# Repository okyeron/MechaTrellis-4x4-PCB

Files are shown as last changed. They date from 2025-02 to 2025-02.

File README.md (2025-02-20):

## MechaTrellis RGB Driver PCB for 4x4 Keypad PCB

PCB files for the MechaTrellis 4x4 keypad PCB. Format is Kicad 8.0 schematic and board layout

### Description

MechaTellis is an Adaptation/Remix of the Adafruit NeoTrellis RGB Driver PCB.  

MechaTellis was designed by Steven Noreyko/denki-oto. Original NeoTrellis design by Limor Fried/Ladyada for Adafruit Industries. 

These run the same NeoTrellis seesaw I2C chip and are fully software compatible with the NeoTrellis boards and projects.

A JST-SH 4-pin connector is included that will give you power+data access. Note JST-SH is smaller than the NeoTrellis JST-PH connector.

From the original NeoTrellis 4x4 boards:  

These 4x4 button pad boards are fully tile-able and communicate over I2C. With 5 address pins, you've got the ability to connect up to 32 together in any arrangement you like. [With our trusty seesaw I2C-to-anything chip](https://learn.adafruit.com/adafruit-seesaw-atsamd09-breakout), you don't even need to manage the NeoPixel driving. That's right! Both the button management and LED driving is completely handled for you all over plain I2C. With both Arduino/C++ and CircuitPython/Python library support, you can use these pads with any and all microcontroller or computer boards.

**You can tile up to 32 boards together by soldering them edge-to-edge and soldering closed the I2C address jumpers, then use one I2C connection for all tiled boards!**

### License

Creative Commons Attribution/Share-Alike, all text above must be included in any redistribution. See license.txt for additional details.

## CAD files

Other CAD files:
MechaTrellis-mounting.dxf

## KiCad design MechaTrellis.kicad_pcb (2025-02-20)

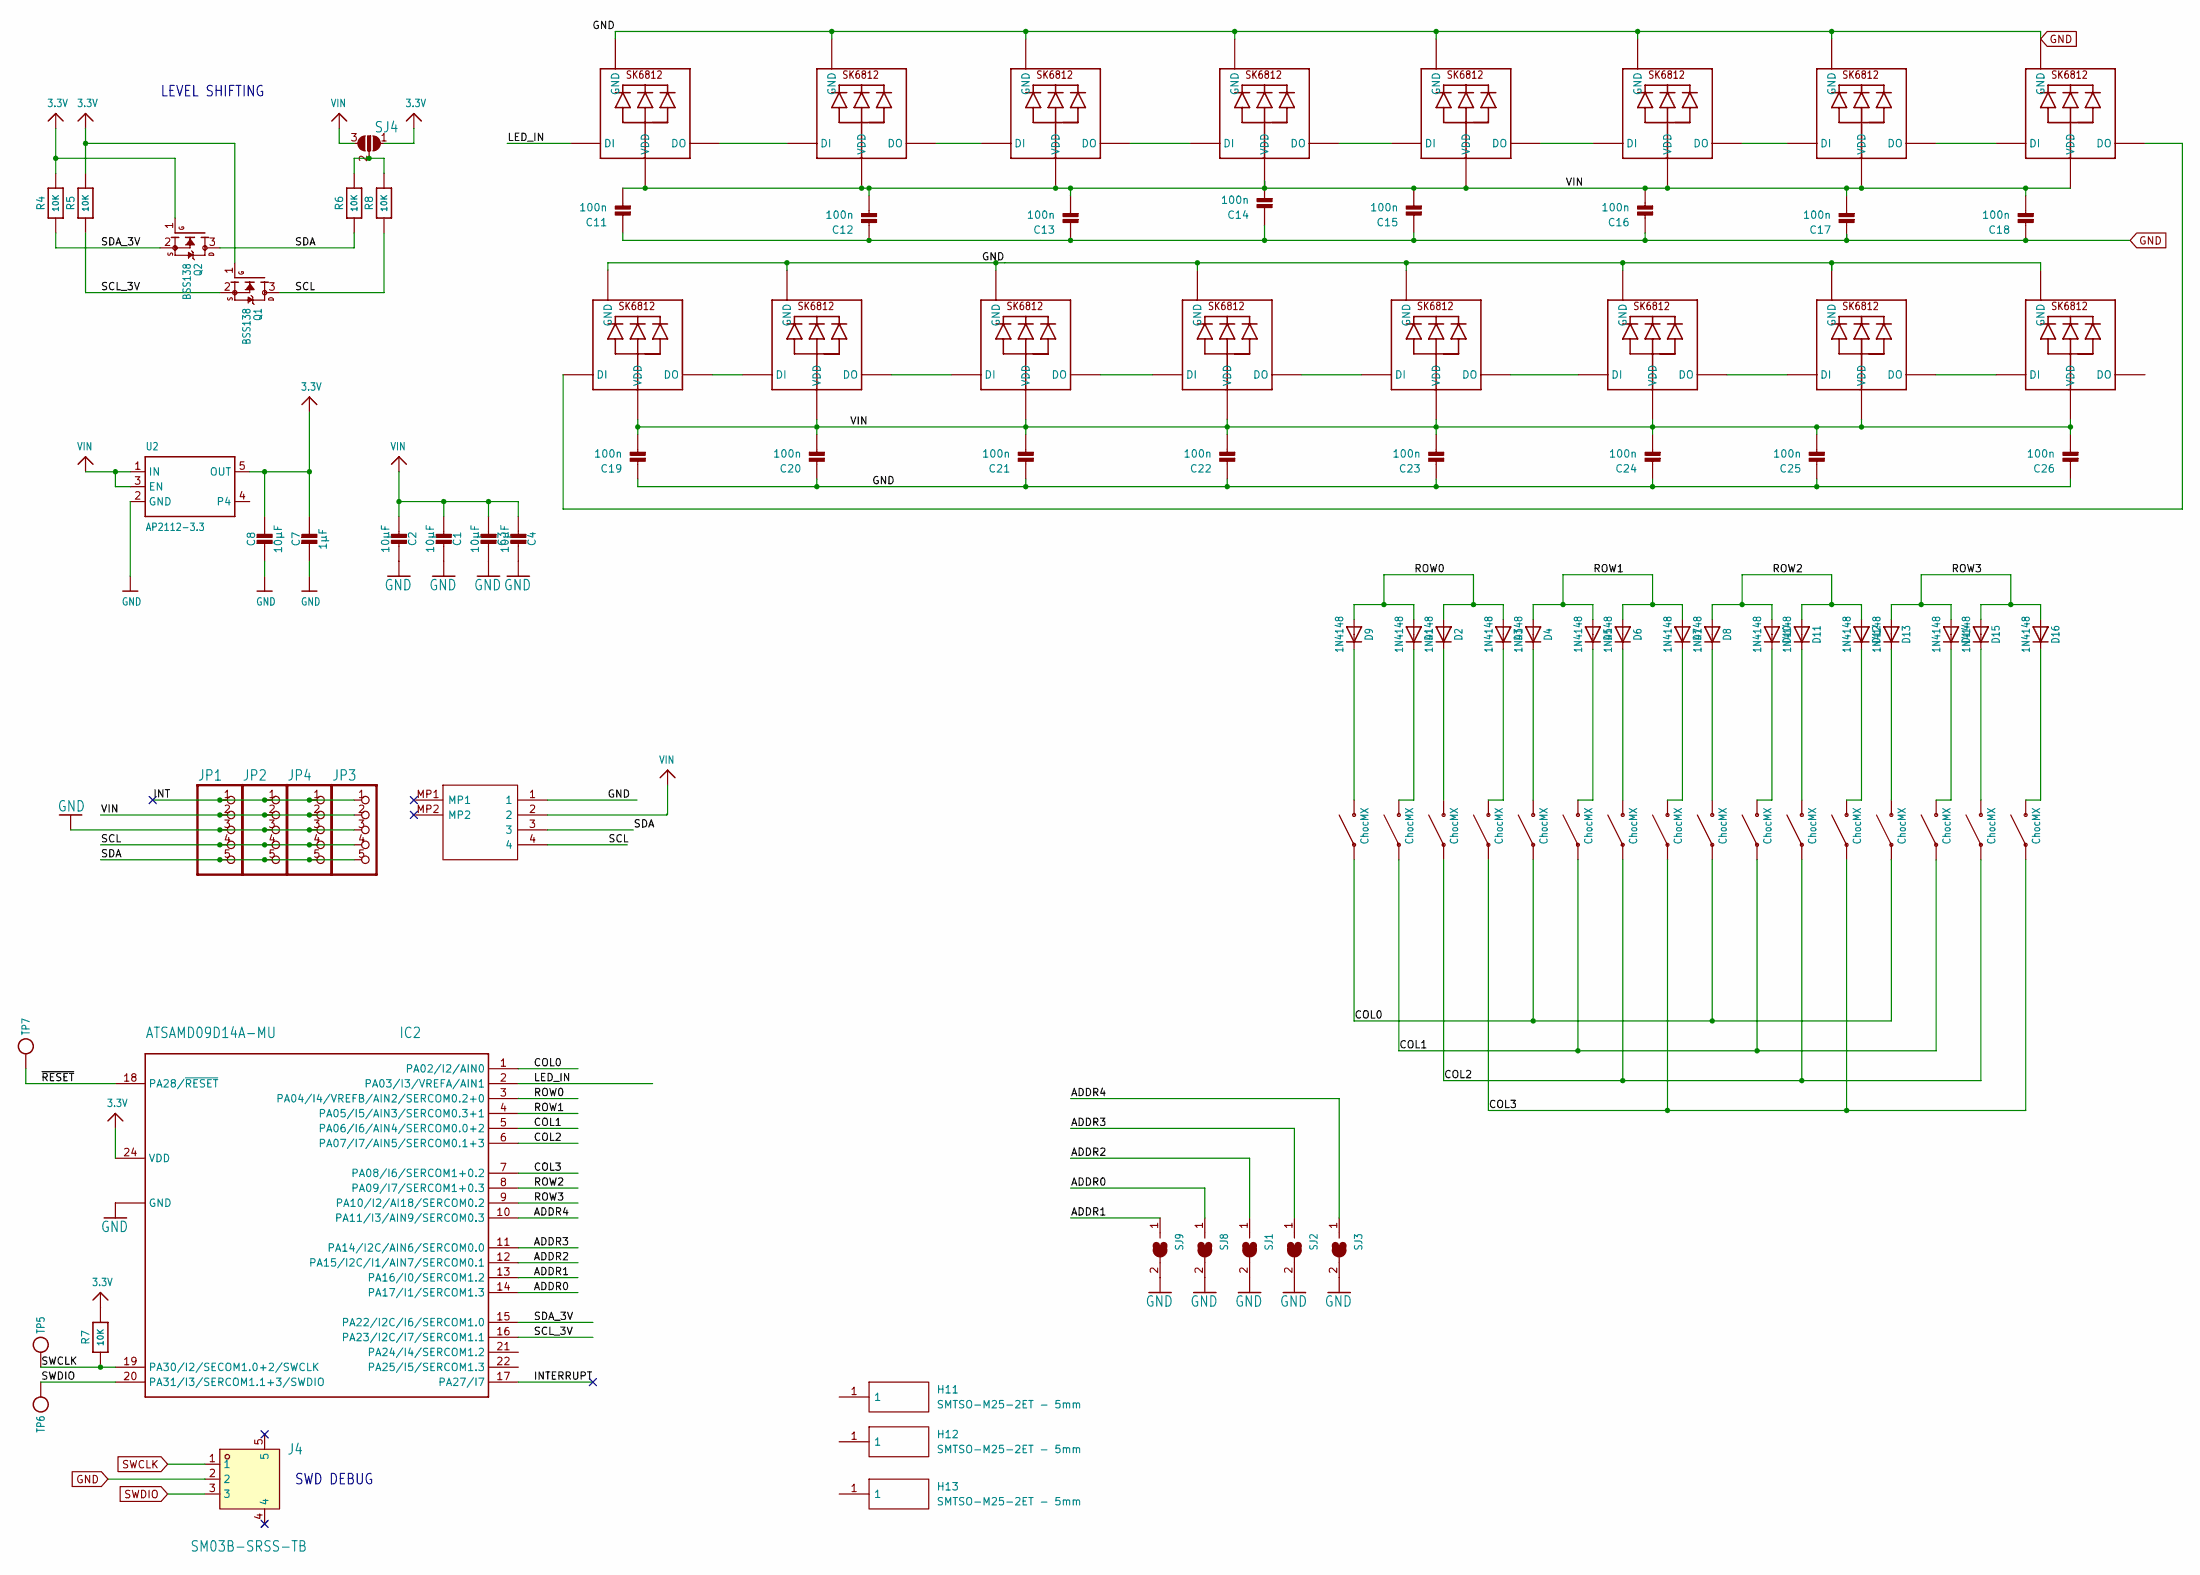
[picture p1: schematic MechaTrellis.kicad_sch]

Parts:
C1, C2, C3, C4, C8: 10µF; C_0805_2012Metric
C7: 1µF; C_0603_1608Metric
C11, C12, C13, C14, C15, C16, C17, C18, C19, C20, C21, C22, C23, C24, C25, C26: 100n; C_0603_1608Metric
D1, D2, D3, D4, D5, D6, D7, D8, D9, D10, D11, D12, D13, D14, D15, D16: 1N4148; SOD-323
H11, H12, H13: SMTSO-M25-2ET - 5mm; SMTSOM252ET; Manufacturer_Part_Number SMTSO-M25-2ET; Mouser Part Number 153-SMTSO-M25-2ET
IC2: ATSAMD09D14A-MU; QFN24_4MM
J4: SM03B-SRSS-TB; SM03B-SRSS-TB_LFSN; Manufacturer_Part_Number SM03B-SRSS-TB(LFSN)
JP1, JP2, JP3, JP4: HEADER-1X5EDGESMT; 5P_EDGECONNECT
K01, K02, K03, K04, K05, K06, K07, K08, K09, K10, K11, K12, K13, K14, K15, K16: ChocMX; Choc_MX_combo
LED1, LED2, LED3, LED4, LED5, LED6, LED7, LED8, LED9, LED10, LED11, LED12, LED13, LED14, LED15, LED16: SK6812MINIE; SK6812-MINI-E
Q1, Q2: BSS138; SOT23-R
R4, R5, R6, R7, R8: 10K; R_0603_1608Metric
SJ1, SJ2, SJ3, SJ8, SJ9: SOLDERJUMPER; SolderJumper-2_P1.3mm_Open_TrianglePad1.0x1.5mm
SJ4: SOLDERJUMPER_2WAY; SolderJumper-3_P1.3mm_Open_RoundedPad1.0x1.5mm
TP5, TP6: TESTPOINTROUND2MM; TESTPOINT_ROUND_2MM
TP7: TESTPOINTROUND1.5MM; TESTPOINT_ROUND_1.5MM
U2: AP2112-3.3; SOT23-5@2
X2: STEMMA_I2C_RASMT; SM04BSRSSTB; Manufacturer_Part_Number SM04B-SRSS-TB

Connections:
3.3V: C7.1, C8.1, IC2.24 (VDD), Q1.1 (G), Q2.1 (G), R4.2, R5.2, R7.2, SJ4.1, U2.5 (OUT)
/ADDR0: IC2.14 (PA17/I1/SERCOM1.3), SJ8.1
/ADDR1: IC2.13 (PA16/I0/SERCOM1.2), SJ9.1
/ADDR2: IC2.12 (PA15/I2C/I1/AIN7/SERCOM0.1), SJ1.1
/ADDR3: IC2.11 (PA14/I2C/AIN6/SERCOM0.0), SJ2.1
/ADDR4: IC2.10 (PA11/I3/AIN9/SERCOM0.3), SJ3.1
/COL0: IC2.1 (PA02/I2/AIN0), K01.SW1, K05.SW1, K09.SW1, K13.SW1
/COL1: IC2.5 (PA06/I6/AIN4/SERCOM0.0+2), K02.SW1, K06.SW1, K10.SW1, K14.SW1
/COL2: IC2.6 (PA07/I7/AIN5/SERCOM0.1+3), K03.SW1, K07.SW1, K11.SW1, K15.SW1
/COL3: IC2.7 (PA08/I6/SERCOM1+0.2), K04.SW1, K08.SW1, K12.SW1, K16.SW1
/INT: JP1.1, JP2.1, JP3.1, JP4.1
/INTERRUPT: IC2.17 (PA27/I7)
/LED_IN: IC2.2 (PA03/I3/VREFA/AIN1), LED1.4-DIN (DI)
/ROW0: D1.A, D2.A, D3.A, D9.A, IC2.3 (PA04/I4/VREFB/AIN2/SERCOM0.2+0)
/ROW1: D4.A, D5.A, D6.A, D7.A, IC2.4 (PA05/I5/AIN3/SERCOM0.3+1)
/ROW2: D8.A, D10.A, D11.A, D12.A, IC2.8 (PA09/I7/SERCOM1+0.3)
/ROW3: D13.A, D14.A, D15.A, D16.A, IC2.9 (PA10/I2/AI18/SERCOM0.2)
/SCL: JP1.4, JP2.4, JP3.4, JP4.4, Q1.3 (D), R8.1, X2.4
/SCL_3V: IC2.16 (PA23/I2C/I7/SERCOM1.1), Q1.2 (S), R5.1
/SDA: JP1.5, JP2.5, JP3.5, JP4.5, Q2.3 (D), R6.1, X2.3
/SDA_3V: IC2.15 (PA22/I2C/I6/SERCOM1.0), Q2.2 (S), R4.1
/~RESET: IC2.18 (PA28/~RESET), TP7.P$1
GND: C1.1, C2.1, C3.1, C4.1, C7.2, C8.2, C11.1, C12.1, C13.1, C14.1, C15.1, C16.1, C17.1, C18.1, C19.1, C20.1, C21.1, C22.1, C23.1, C24.1, C25.1, C26.1, IC2.23 (GND), IC2.THERM (GND), JP1.3, JP2.3, JP3.3, JP4.3, LED1.3-GND (GND), LED2.3-GND (GND), LED3.3-GND (GND), LED4.3-GND (GND), LED5.3-GND (GND), LED6.3-GND (GND), LED7.3-GND (GND), LED8.3-GND (GND), LED9.3-GND (GND), LED10.3-GND (GND), LED11.3-GND (GND), LED12.3-GND (GND), LED13.3-GND (GND), LED14.3-GND (GND), LED15.3-GND (GND), LED16.3-GND (GND), SJ1.2, SJ2.2, SJ3.2, SJ8.2, SJ9.2, U2.2 (GND), X2.1; also elsewhere on the board
unnamed: D1.C, K02.SW2
unnamed: D2.C, K03.SW2
unnamed: D3.C, K04.SW2
unnamed: D4.C, K05.SW2
unnamed: D5.C, K06.SW2
unnamed: D6.C, K07.SW2
unnamed: D7.C, K08.SW2
unnamed: D8.C, K09.SW2
unnamed: D9.C, K01.SW2
unnamed: D10.C, K10.SW2
unnamed: D11.C, K11.SW2
unnamed: D12.C, K12.SW2
unnamed: D13.C, K13.SW2
unnamed: D14.C, K14.SW2
unnamed: D15.C, K15.SW2
unnamed: D16.C, K16.SW2
unnamed: LED1.2-OUT (DO), LED2.4-DIN (DI)
unnamed: LED2.2-OUT (DO), LED3.4-DIN (DI)
unnamed: LED3.2-OUT (DO), LED4.4-DIN (DI)
unnamed: LED4.2-OUT (DO), LED5.4-DIN (DI)
unnamed: LED5.2-OUT (DO), LED6.4-DIN (DI)
unnamed: LED6.2-OUT (DO), LED7.4-DIN (DI)
unnamed: LED7.2-OUT (DO), LED8.4-DIN (DI)
unnamed: LED8.2-OUT (DO), LED9.4-DIN (DI)
unnamed: LED9.2-OUT (DO), LED10.4-DIN (DI)
unnamed: LED10.2-OUT (DO), LED11.4-DIN (DI)
unnamed: LED11.2-OUT (DO), LED12.4-DIN (DI)
unnamed: LED12.2-OUT (DO), LED13.4-DIN (DI)
unnamed: LED13.2-OUT (DO), LED14.4-DIN (DI)
unnamed: LED14.2-OUT (DO), LED15.4-DIN (DI)
unnamed: LED15.2-OUT (DO), LED16.4-DIN (DI)
unnamed: R6.2, R8.2, SJ4.2
SWCLK: IC2.19 (PA30/I2/SECOM1.0+2/SWCLK), R7.1, TP5.P$1; also elsewhere on the board
SWDIO: IC2.20 (PA31/I3/SERCOM1.1+3/SWDIO), TP6.P$1; also elsewhere on the board
VIN: C1.2, C2.2, C3.2, C4.2, C11.2, C12.2, C13.2, C14.2, C15.2, C16.2, C17.2, C18.2, C19.2, C20.2, C21.2, C22.2, C23.2, C24.2, C25.2, C26.2, JP1.2, JP2.2, JP3.2, JP4.2, LED1.1-VDD (VDD), LED2.1-VDD (VDD), LED3.1-VDD (VDD), LED4.1-VDD (VDD), LED5.1-VDD (VDD), LED6.1-VDD (VDD), LED7.1-VDD (VDD), LED8.1-VDD (VDD), LED9.1-VDD (VDD), LED10.1-VDD (VDD), LED11.1-VDD (VDD), LED12.1-VDD (VDD), LED13.1-VDD (VDD), LED14.1-VDD (VDD), LED15.1-VDD (VDD), LED16.1-VDD (VDD), SJ4.3, U2.1 (IN), U2.3 (EN), X2.2

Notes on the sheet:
SWD DEBUG
LEVEL SHIFTING

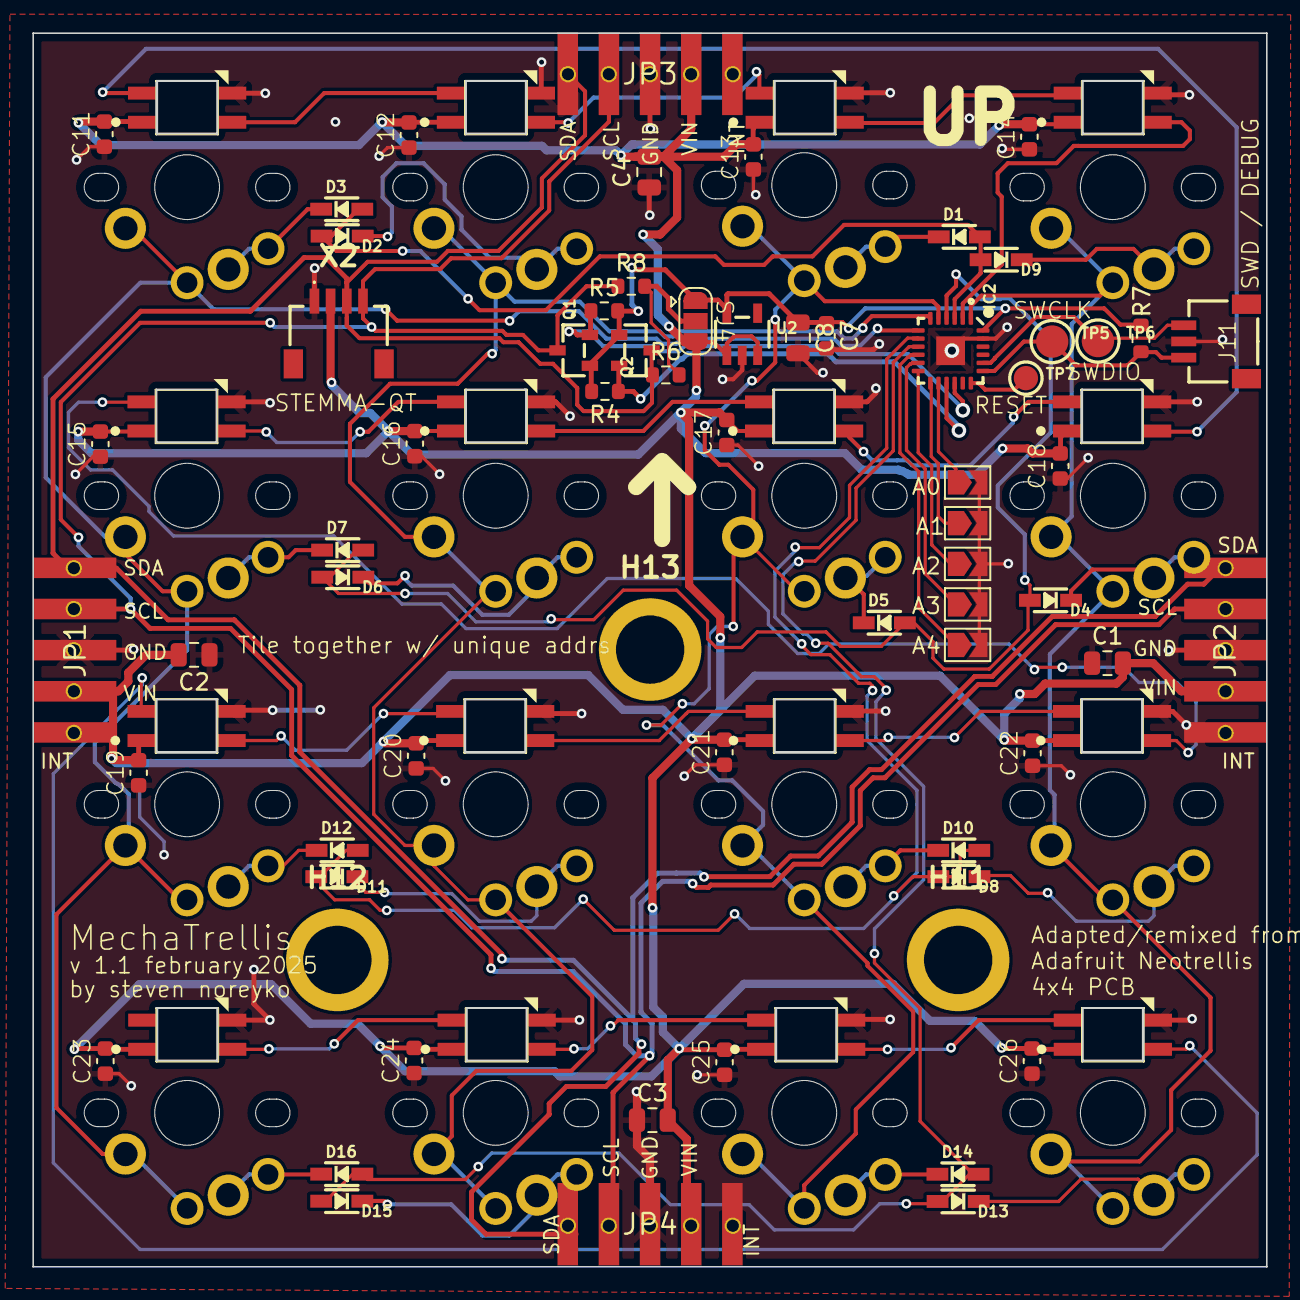
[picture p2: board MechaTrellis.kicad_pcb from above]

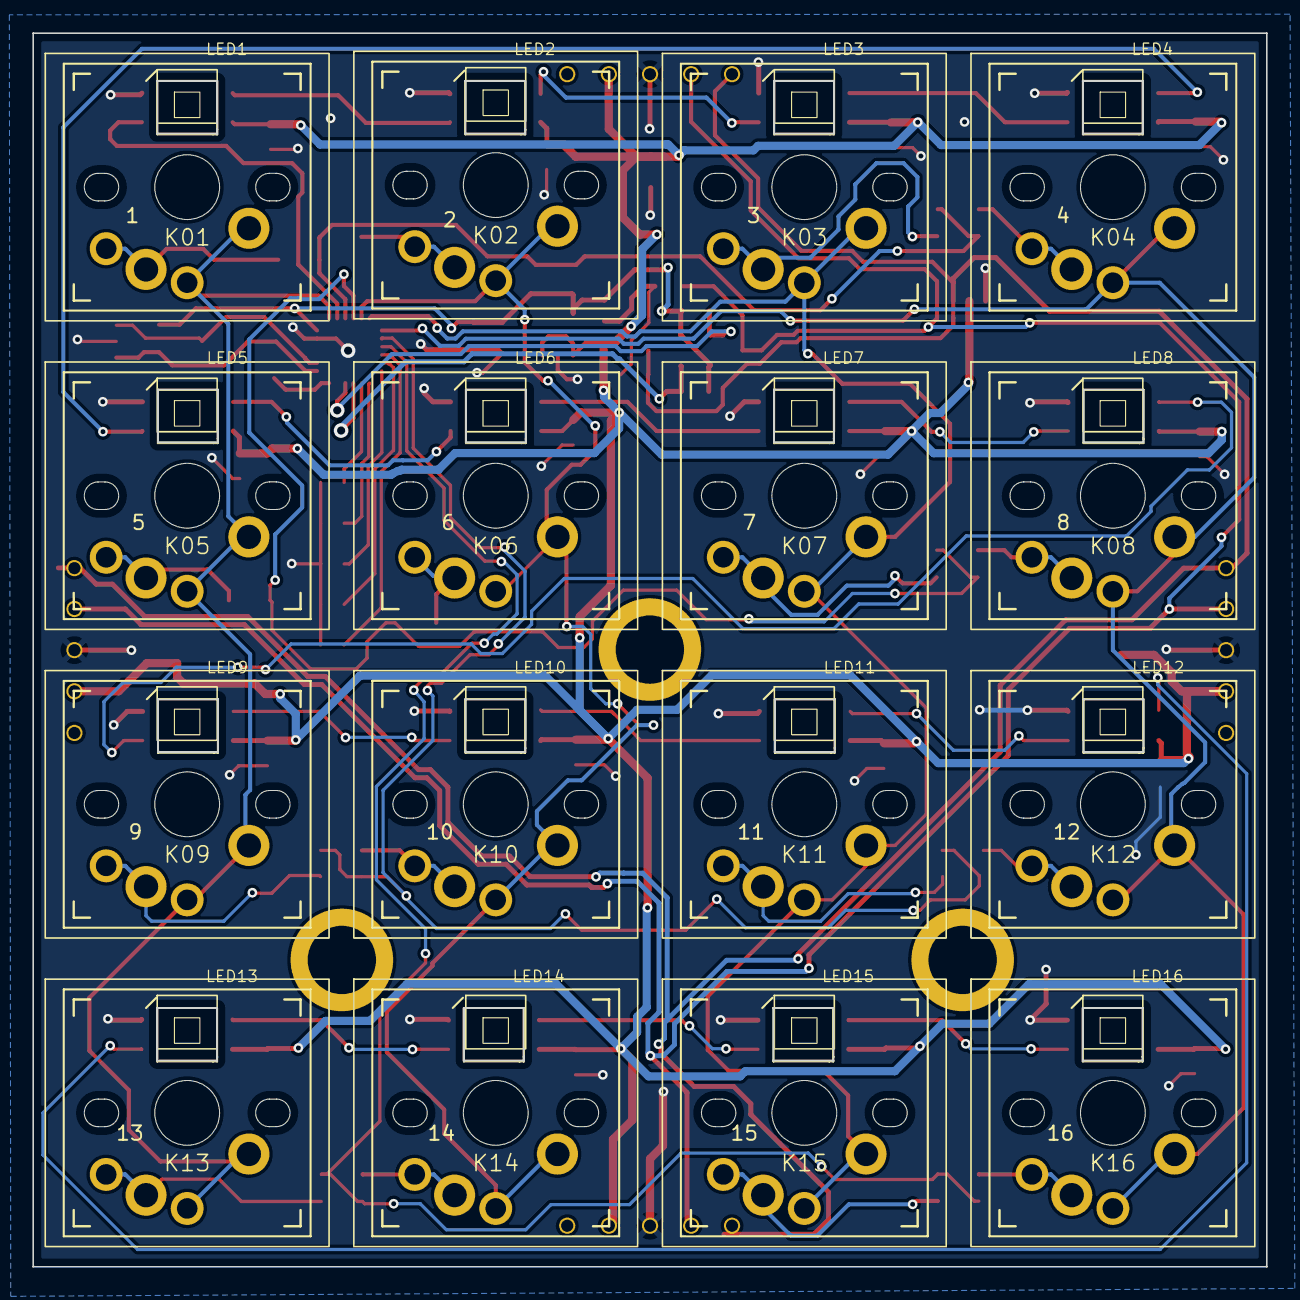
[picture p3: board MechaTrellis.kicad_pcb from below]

Board: 2 copper layers, 76.2 x 76.2 mm, 112 parts (32 on the bottom side), 57 nets.

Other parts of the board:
GND: (no value)
GND#2, GND#3: (no value)
J11: SM03B-SRSS-TB; SM03B-SRSS-TB_LFSN
SCL: (no value)
SCL#2, SCL#3, SCL#4: (no value)
SDA: (no value)
SDA#2, SDA#3, SDA#4: (no value)
VIN: (no value)
VIN#2, VIN#3, VIN#4: (no value)

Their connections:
GND: J11.2; also elsewhere on the board
SWCLK: J11.1; also elsewhere on the board
SWDIO: J11.3; also elsewhere on the board
